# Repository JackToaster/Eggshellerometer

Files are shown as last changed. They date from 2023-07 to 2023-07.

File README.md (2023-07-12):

# Eggshellerometer


An acceleration-logging smart egg for egg drop experiments.

## Features
The goal of this project is to create a logging high-acceleration accelerometer. It can be used in place of an egg for egg-drop type experiments, and also as an open-source, hackable tool for recording high-acceleration events such as impacts or rocket launches. 
- 200G Accelerometer recording data at up to 3.2kHz (ADXL375)
- Built-in wifi/bluetooth with an ESP32-S3 microcontroller - allows connection to a phone/tablet companion app to visualize data
- tiny 0.5" OLED display to display information
- Tiny form factor - 30x50mm PCB which fits in a case the size of a large chicken egg
- Battery powered with a USB-C connector for charging/updating
- Configurable wakeup threshold to record acceleration events over a long period of time without draining battery
- Low cost, <$20 assembled in small quantities
- Open-source hardware and firmware (WIP)
- No chickens harmed in the making

## Status of the project
Currently, only the electrical hardware has been designed. I will include firmware, CAD & 3D printing files for enclosures, and any other information in this repository as I create them (Likely after I receive the first batch of prototypes).

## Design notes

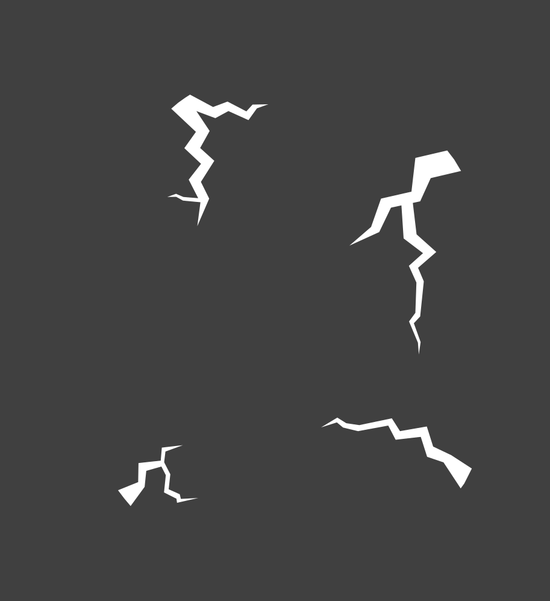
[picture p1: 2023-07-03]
silkscreen-art.png

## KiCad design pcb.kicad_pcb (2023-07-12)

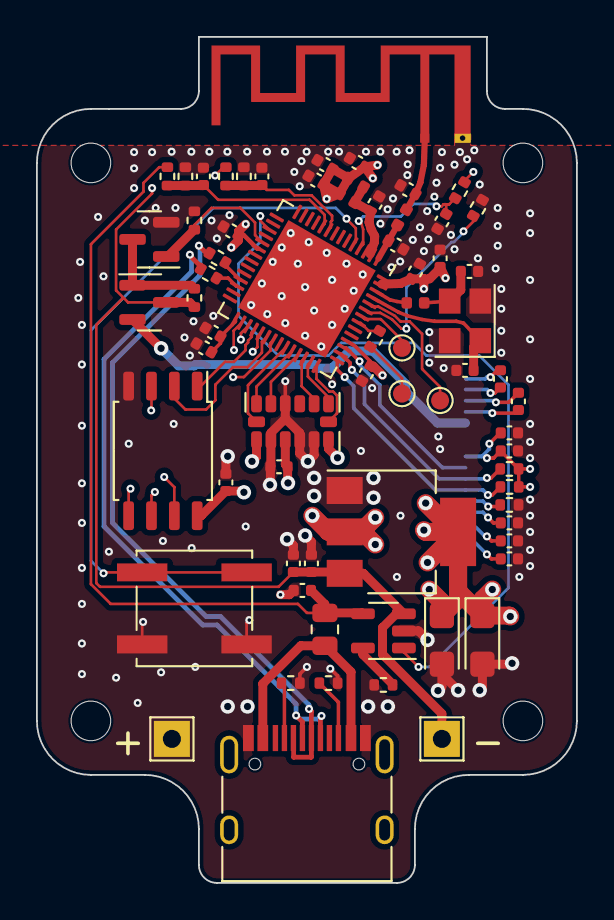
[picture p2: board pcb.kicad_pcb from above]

Board: 4 copper layers, 30.0 x 47.0 mm, 74 parts (1 on the bottom side), 54 nets.

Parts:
AE2: PCB Antenna; Texas_SWRA117D_2.4GHz_Left
C7, C28, C30: 10u; C_0402_1005Metric
C8, C20: 10u tantalum; CP_EIA-3216-10_Kemet-I
C9, C10, C13, C18, C22, C23, C24, C26, C29, C32, C38, C39: 100n; C_0402_1005Metric
C11, C12, C16: 4u7; C_0402_1005Metric
C14, C17, C25, C27, C31, C33: 1u; C_0402_1005Metric
C15: 2u2; C_0402_1005Metric
C34, C35: 22p; C_0402_1005Metric
C36: 4p7; C_0402_1005Metric
C37: 3p3; C_0402_1005Metric
FB1: 100R@100MHz; R_0805_2012Metric
H1, H2, H3, H4: MountingHole; MountingHole_2.2mm_M2
J1: USB_C_Receptacle_USB2.0; USB_C_Receptacle_HRO_TYPE-C-31-M-12
J2: OLED; FPC_14
L1, L2: 3.9nH; L_0402_1005Metric
L3: 15nH; L_0402_1005Metric
L4: 1.8nH; L_0402_1005Metric
Q3: 2N7002; SOT-23
Q4: Si2301CDS; SOT-23
R3, R5, R8, R10, R11, R13, R14: 10k; R_0402_1005Metric
R6, R7: 5k1; R_0402_1005Metric
R9: 560k; R_0402_1005Metric
R15, R16, R17, R18: 120k; R_0402_1005Metric
R20: 470; R_0402_1005Metric
R21, R22: 0R; R_0402_1005Metric
SW1: SW_Push; SW_Push_1P1T_NO_CK_KSC7xxJ
TP1: Batt+; TestPoint_THTPad_2.0x2.0mm_Drill1.0mm
TP2: Batt-; TestPoint_THTPad_2.0x2.0mm_Drill1.0mm
TP3: TXD; TestPoint_Pad_D1.0mm
TP4: RXD; TestPoint_Pad_D1.0mm
TP5: BOOT1; TestPoint_Pad_D1.0mm
U1: ADXL375; LGA-14_3x5mm_P0.8mm_LayoutBorder1x6y
U3: AMS1117-3.3; SOT-223-3_TabPin2
U4: MCP73831-2-OT; SOT-23-5
U5: W25Q128JVS; SOIC-8_5.23x5.23mm_P1.27mm
U6: ESP32-S3; QFN-56-1EP_7x7mm_P0.4mm_EP5.6x5.6mm
Y1: 40MHz 15pF; Crystal_SMD_3225-4Pin_3.2x2.5mm

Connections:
+3.3V: C8.1, C10.1, C12.1, C13.1, C20.1, C22.1, C23.1, C26.1, C27.1, C28.1, C30.1, C31.1, C32.1, J2.8, L1.1, L2.1, R10.1, R11.1, R14.1, U1.1 (Vdd_I/O), U1.3 (RES), U1.6 (Vs), U3.2 (VO), U5.8 (VCC), U6.20 (VDD3P3_RTC), U6.46 (VDD3P3_CPU), U6.55 (VDDA), U6.56 (VDDA)
/ANT_RF: AE2.1, C37.1, L4.1
/BOOT: SW1.2, U6.5 (GPIO0/BOOT)
/ESP_RF: C36.1, L4.2, U6.1 (LNA_IN/RF)
/OLED/C1N: C14.2, J2.4
/OLED/C1P: C14.1, J2.3
/OLED/C2N: C17.2, J2.2
/OLED/C2P: C17.1, J2.1
/OLED/IREF: J2.12, R9.1
/OLED/OLED-VBAT: J2.5, Q4.2 (S)
/OLED/VCC: C16.1, C18.1, J2.14
/OLED/VCOMH: C15.1, J2.13
/VDD_SPI: C24.1, C25.1, U6.29 (VDD_SPI)
ACCEL-INT1: U1.8 (INT1), U6.41 (GPIO36)
ACCEL-INT2: U1.9 (INT2), U6.40 (GPIO35)
ACCEL-SCK: U1.14 (SCL/SCLK), U6.37 (SPICLK_P/GPIO47)
ACCEL-SDI: U1.13 (SDA/SDI/SDIO), U6.38 (GPIO33)
ACCEL-SDO: U1.12 (SDO/ADDR), U6.39 (GPIO34)
ACCEL-nCS: U1.7 (~CS), U6.42 (GPIO37)
CHARGE_STAT: U4.1 (STAT), U6.17 (GPIO12/ADC2_CH1)
FLASH-CLK: U5.6 (CLK), U6.33 (SPICLK/GPIO30)
FLASH-D: U5.5 (DI(IO0)), U6.35 (SPID/GPIO32)
FLASH-HD: U5.7 (IO3), U6.30 (SPIHD/GPIO27)
FLASH-Q: U5.2 (DO(IO1)), U6.34 (SPIQ/GPIO31)
FLASH-WP: U5.3 (IO2), U6.31 (SPIWP/GPIO28)
FLASH-nCS: U5.1 (~CS), U6.32 (SPICS0/GPIO29)
GND: AE2.2, C7.2, C8.2, C9.2, C10.2, C11.2, C12.2, C13.2, C15.2, C16.2, C18.2, C20.2, C22.2, C23.2, C24.2, C25.2, C26.2, C27.2, C28.2, C29.2, C30.2, C31.2, C32.2, C33.2, C34.1, C35.2, C36.2, C37.2, C38.2, C39.2, J1.A1 (GND), J1.A12 (GND), J1.B1 (GND), J1.B12 (GND), J2.7, Q3.2 (S), R3.2, R5.2, R6.2, R7.1, R9.2, R13.2, R16.2, R18.2, SW1.1, TP2.1, U1.2 (GND), U1.4 (GND), U1.5 (GND), U1.11 (RES), U3.1 (GND), U4.2 (V_{SS}), U5.4 (GND), U6.57 (GND), Y1.2, Y1.4
I2C_SCL: J2.10, R11.2, U6.44 (MTCK/JTAG/GPIO39)
I2C_SDA: J2.11, R10.2, U6.43 (GPIO38)
unnamed: C34.2, L3.1, Y1.3
unnamed: FB1.1, J1.A4 (VBUS), J1.A9 (VBUS), J1.B4 (VBUS), J1.B9 (VBUS)
unnamed: J1.A5 (CC1), R6.1
unnamed: J1.B5 (CC2), R7.2
unnamed: Q3.3 (D), Q4.1 (G), R8.2
unnamed: R20.2, TP3.1
unnamed: R5.1, U4.5 (PROG)
unnamed: C33.1, R14.2, U6.4 (CHIP_PU/RESET)
unnamed: R22.1, U6.25 (GPIO19/USB_D-/ADC2_CH8)
unnamed: R21.1, U6.26 (GPIO20/USB_D+/ADC2_CH9)
unnamed: R13.1, U6.51 (GPIO45)
unnamed: TP5.1, U6.52 (GPIO46)
unnamed: TP4.1, U6.50 (U0RXD/PROG/GPIO44)
unnamed: R20.1, U6.49 (U0TXD/PROG/GPIO43)
unnamed: C35.1, U6.53 (XTAL_N), Y1.1
unnamed: L3.2, U6.54 (XTAL_P)
OLED_ENABLE: Q3.1 (G), R3.1, U6.19 (GPIO14/ADC2_CH3)
OLED_RESET: J2.9, U6.45 (MTDO/JTAG/GPIO40)
USB_D+: J1.A6 (D+), J1.B6 (D+), R21.2
USB_D-: J1.A7 (D-), J1.B7 (D-), R22.2
USB_VBUS: C11.1, FB1.2, R17.1, U4.4 (V_{DD})
VBAT: C7.1, C9.1, Q4.3 (D), R8.1, R15.1, TP1.1, U3.3 (VI), U4.3 (V_{BAT})
VBAT_MEAS: C39.1, R15.2, R16.1, U6.9 (GPIO4/ADC1_CH3)
VBUS_MEAS: C38.1, R17.2, R18.1, U6.10 (GPIO5/ADC1_CH4)
VDD3P3: C29.1, L1.2, L2.2, U6.2 (VDD3P3), U6.3 (VDD3P3)

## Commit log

2023-07-02 inital layout
    [OLED.kicad_sch, leds.kicad_sch, pcb.kicad_pcb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]
2023-07-03 Added silkscreen art and fixed overlapping things
    [pcb.kicad_pcb]
2023-07-12 Use bare ESP32 chip instead of module (#1)
    * fixed library issues
    * add submodules to CI/CD
    * fix yaml syntax
    * added part numbers
    * Bare ESP layout
    * fix erc/drc
    * fix overlap
    * added part numbers
    * fixed layout
    [OLED.kicad_sch, leds.kicad_sch, pcb.kicad_pcb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]
